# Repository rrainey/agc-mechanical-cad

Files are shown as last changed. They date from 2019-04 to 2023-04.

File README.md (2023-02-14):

# AGC Mechanical CAD Models and Drawings

This repository contains downloadable Autodesk Fusion 360 and STEP CAD models of many Apollo Guidance Computer components.

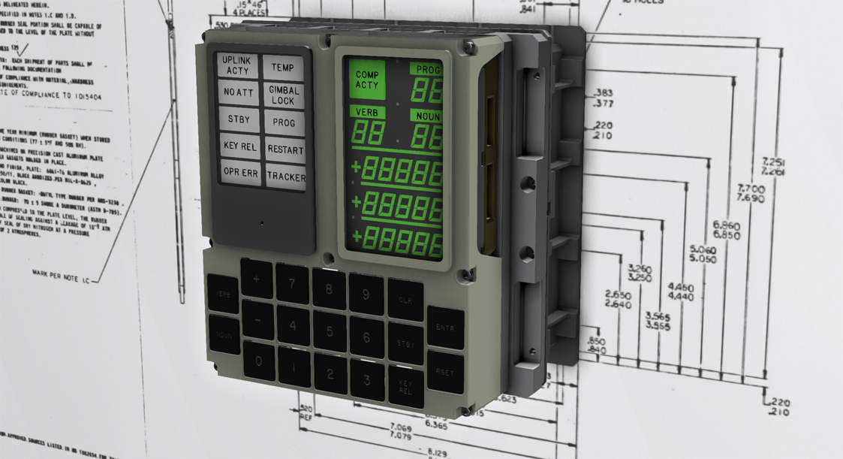
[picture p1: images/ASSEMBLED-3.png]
Assembled Model


## Introduction

The Apollo Guidance Compuer (AGC) is one of the critical inventions that made the U.S. moon landings possible. AGC's were installed in both the Apollo Command Module and Lunar Excursion Module. MIT and NASA archives, as well as important contributions from some
of the original team members have given us a rich set of detail about how this computer was constructed.

The [Virtual AGC Project](https://www.ibiblio.org/apollo/) was originally focused on software simulation 
of the AGC. 

Over time, the Virtual AGC Project branched in many directions. Simulation projects for other space related guidance systems
were researched; hybrid hardware and software models of the AGC have been created. The circuitry of the AGC has been reproduced using modern IC components. 

More recently, Ron Burkey, the Virtual AGC project's leader, scanned, cataloged, and published
the [original MIT electrical and mechanical drawings of the AGC](https://www.ibiblio.org/apollo/ElectroMechanical.html). This detailed catalog has made it possible to construct CAD models of the AGC's mechanical components.

The content in this repository represents my work using Fusion 360 to generate CAD models from those original drawings using modern CAD/CAM tooling.

## How These Models Were Created

[Autodesk's Fusion 360](https://www.autodesk.com/products/fusion-360/students-teachers-educators) was used exclusively to create these models. 
While Fusion 360 is not open source software, Autodesk offers a no-cost
license to students, makers, and startups. You can obtain your own copy of Fusion 360 and begin editing the .f3d files contained in this project. 
STEP-format CAD models for each component have been exported and included in this project as well. 
Those model files are directly usable by many other CAD modeling and 3D-printing systems.

Panel markings use an engraving font face called "Gorton". Eugene Dorr created OTF and TTF versions of these fonts. These files can be downloaded from https://github.com/ehdorrii/dsky-fonts 

### Archived Drawings Collections are Incomplete

It is worth saying that the source archives for this project are incomplete.
The AGC evolved substantially over its lifetime  -- descriptions of many changes
are captured in Engineering Change Proposals (ECPs) which may or may not be completely
reflected in the archived drawings. Also, there are gaps in the drawing collections.  
This requires reconstruction of some parts in order to develop a more complete model.

## Is This a Complete AGC Model of what is Available?

No. I am releasing what I have transcribed so far. That amounts to roughly twenty models. Each is currently 90-100% completely encoded from the original engineering documents.

I'm working to maintain engineering precision wherever I can. Errors undoubtedly exist, and I'm my own Quality
Assurance department currently. In other words, use at your own risk.

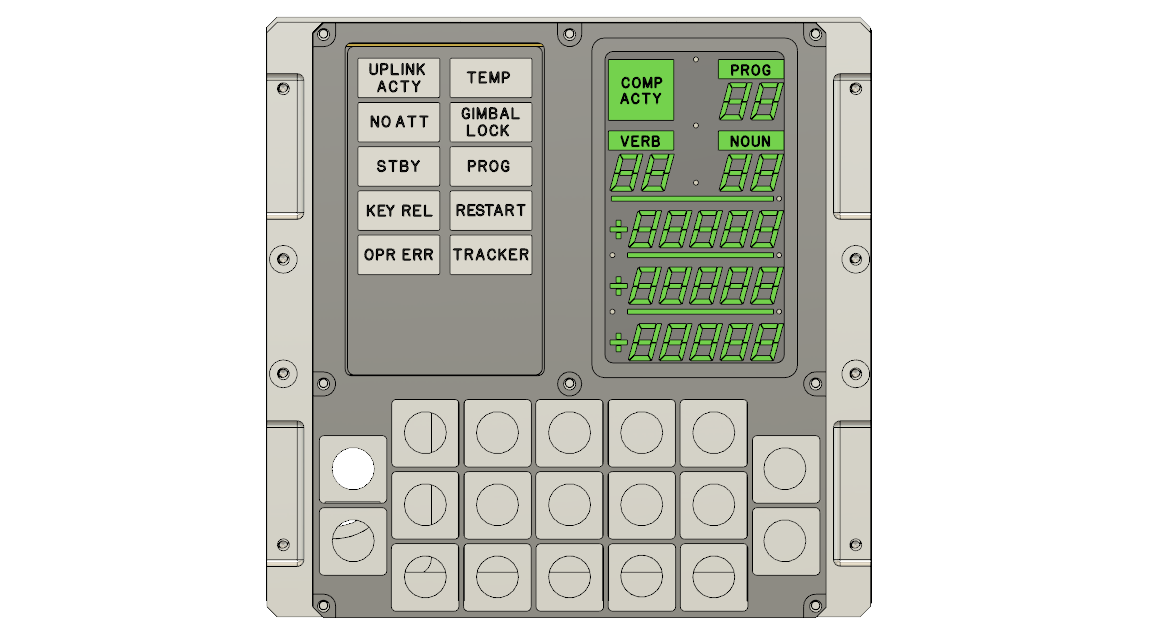
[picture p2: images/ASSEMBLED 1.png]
Assembled Model


## The DSKY: Pushbutton Springs and "Fire Fixes"

An example illustrating the resources and gaps we work from is the DSKY pushbutton
switch. There are three distinct part numbers representing different variants of
the pushbutton switch: 2003875, 2003894, and 2003984.  Of those three only 2003875
has a mostly complete set of drawings.

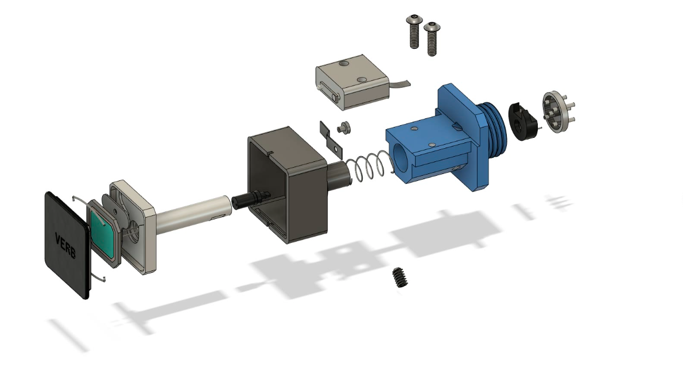
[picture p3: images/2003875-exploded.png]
An AGC Pushbutton - 2003875


The gap starts with the cap housing assembly.  The cap housing sits behind the
actual key cap. It holds the cap in place and serves to guide the depressed key into contact
with the actual switch. The drawing for that cap housing assembly is - so far - missing. Also missing is a
drawing for the leaf spring that's mounted at the back of that assembly.  There's a rivet
attaching the spring to the housing, too.  The exploded drawing you see above represents a best guess of the dimensions of the missing parts.

On my to-do list for this project is to build a 
compendium of what parts we have, where
we had complete drawings to work from, and
where the gaps and guesses are.

[This Raytheon contractor report](https://ntrs.nasa.gov/citations/19700015154) describes important
upgrades to the DSKY that are not completely captured in the archived drawing collections:

>h. DSKY pushbutton switch spring - Due to failures of the DSKY
pushbutton switch spring (shown in Figure 3-6) a failure analysis and
design review of the spring was performed. The failure inalysis and
design review indicated that in normal use the spring could crack at
points of stress concentration. As a result, a new spring was designed.
As shown in the drawing, the new spring replaces the present
spring in form, fit, and function with tighter geometric constraints.

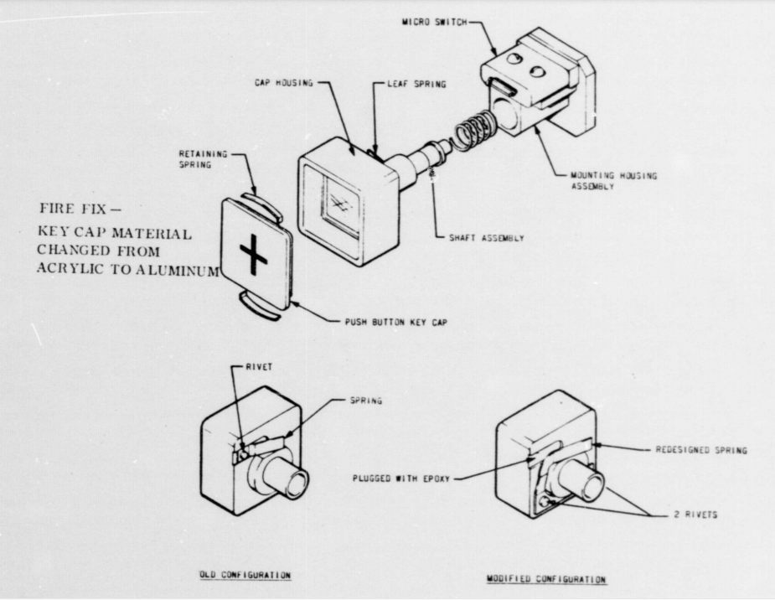
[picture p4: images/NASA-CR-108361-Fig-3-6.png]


>The wraparound design of the new spring lengthens the spring arm
to reduce stress and allows the new spring to be incorporated in the existing
pushbutton switch design. The thickness of the spring has changed from
0.010 to 0.018 inch to retain the same spring rate. The material of the
new spring is the same as that for the present spring but is specially
hardened to a minimum of 270,000 lbf/in^2 U.T.S. to increase the fatigue
strength of the spring.
>
>i. DSKY fire fix - As a result of the
 flammability study performed as authorized by CCA 497-0428, the DSKY alarm indicator(P/N 1006387-003) and DSKY pushbutton caps (P/N 1006353) requiredmaterial changes as follows (see Figure 3-7)
>
>>1. alarm indicator - affix nonflammable nonreflective glass
cover with an aluminum frame as an integral part of the indicator panel
>>2. DSKY pushbutton caps - rep:ace the acrylic cap with one of aluminum having etched and acrylic filled characters.

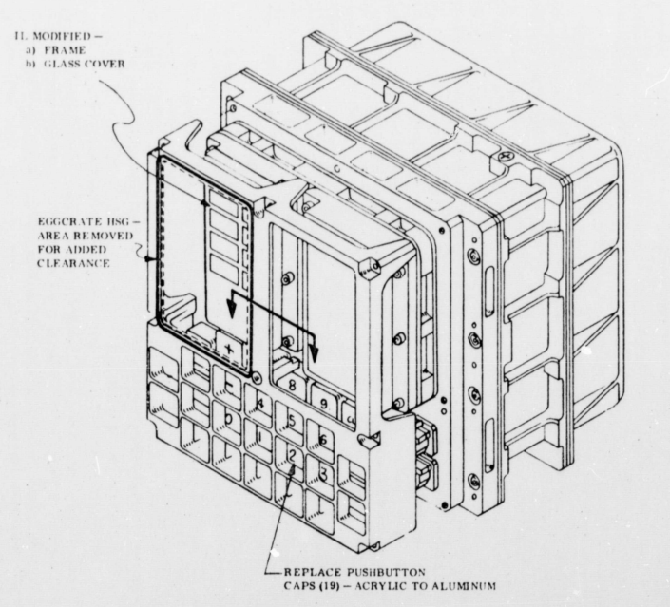
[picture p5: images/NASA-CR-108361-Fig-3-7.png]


>j. Teflon - (not included here, as it dosen't directly apply to the Fusion CAD models, but Teflon coatings were added to reduce the tendency for pushbuttons operate less smoothly due to wear.)

These changes are listed here but not yet integrated into this CAD project.

## My Background

My name is Riley Rainey. I'm a software developer by profession. I spent a number of years building aerospace simulations as my day job.
I'm not a Professional Engineer by any stretch, but my work in simulation put me in close contact with CAD designers and CAD systems. I used AutoCad many years ago, but my exposure to Fusion 360 began with this project.

## Getting Support

There's no official support available, but if you notice a problem or have a request for a specific drawing to be
transcribed, [create an issue](https://github.com/rrainey/agc-mechanical-cad/issues) in this GitHub project.

  
This work is licensed under a [Creative Commons Attribution-ShareAlike 4.0 International License](http://creativecommons.org/licenses/by-sa/4.0/).

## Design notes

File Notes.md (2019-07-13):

Over time the AGC Block II DSKY had multiple versions. There's also different variants installed in the CSM and LEM.

For now, I am focusing on modeling the versions used in the Apollo 17 CSM DSKY (see https://www.ibiblio.org/apollo/2014999-181.html)

I'm collecting notes and questions regarding each drawing set that I used to create this model.

### GENERAL NOTES

Dowel pins are generally not included in these models.

Holes for screw thread inserts are modeled as the actual screw hole.

### 1001489-59 SCREW

Eight of these screws secure the Front Cover on the DSKY ASSEMBLY (in 2003994J).  The latest specification drawing for these screws we currently have is 1001489 "C" - the highest screw suffix on that drawing 
is "-57", not "-59". I did a bit of reverse engineering to reconstruct the "-59" part: #6 threads are used and the length I chose is 1.500 inches.  
At some point I will try to locate a replacement off-the-shelf part from Grainger or Digikey.

### 1006387D - INDICATOR, ALARM

The inner constructon of this assembly is not fully documented in the AGC drawings. I'm generating an "exact" version based on the drawing, and a "reconstructed" version that would be based on building a simulated version from
modern parts.

Portions of the connector at the back of the part remain to be modeled.

On the back, there's a channel marked "0.615 MIN" (B3) - a more "to scale" value of 0.515 MIN has been used in the model.

### 2004699A - COVER

There are apparently two variants of this part, but the drawing does not call these out. The drawing depicts a part with a "short window" -- intended for the Status and Warning light assembly, however a 2004699-001 version is also called out for the E/L & Cover Assembly (2003988B). 
The Status cover assembly(2003897C) calls for either part 2004699-000 or 2004699-001, depending on the variant of the assembly. Based on the two assembly drawing referencing 2004699, I'm inferring that
the -000 variant has the "short window" and -001 is the "tall window". It's not difficult to reconstruct the part geometry for the tall window, but I'm wondering why it is missing in the source part drawing.

### 2004746-001 INDICATOR, DIGITAL (THERMAL-VAC)  (a.k.a. 1006315G)

This is the E/L display indicator for the DSKY. The drawing indicated 2004647 is just a relabeled Block I part, 1006315-001. 1006315G includes dimensions of the E/L display elements and the outline of the assembly, but lacks
details on the internals. The Gorton fonts used in this model originates from Eugene

### 2004923 PLATE, CONNECTOR

[COMPLETE] Screw thread inserts are modeled as a hole for the intended screw. Dowel pins are not modeled. The drawing is slightly out of scale at the middle of the bottom face.

### 2004925 HEADER KEYBOARD MODULE

[COMPLETE] The arrays of holes for the pin insulators aren't explictly marked as laterally centered on the header, but that seems like a reasonable assumption. I have modeled it that way.

### 2004932 JACKING SCREW

[COMPLETE] Both variants are modeled. The modeling of the threading at the tip of the screw isn't quite accurate.

### 2004974D IDM PLATE

[COMPLETE] This is easily the most complex component to model.

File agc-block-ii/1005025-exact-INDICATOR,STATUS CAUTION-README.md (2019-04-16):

thumbnail of model

## thumbnail of model

## 1005025 INDICATOR, STATUS CAUTION - AGC DSKY

This is a model of the Status/Caution Indicator panel of the AGC DSKY.

## Source Drawing(s)

[1005025 sheet 1 of 3](https://archive.org/stream/AgcApertureCardsBatch3Images#mode/1up)

[1005025 sheet 2 of 3](https://archive.org/stream/AgcApertureCardsBatch3Images#page/n1/mode/1up)

[1005025 sheet 3 of 3](https://archive.org/stream/AgcApertureCardsBatch3Images#page/n2/mode/1up)

[2003956](https://archive.org/stream/AgcApertureCardsBatchKeithley#page/n71/mode/1up) AGC DSKY OUTLINE

### Source Drawing Issues

The back view of the assembly on sheet 3 (C2) is out of scale. It is stretched laterally.

### Next Assembly
N/A

## Known Issues
### Model Discrepancies

1. The source drawing does not provide enough detail to accurately reconstruct this assembly.

### To Do List

* This model needs to be decomposed into wells for the lights and a front face.
* The electrical connector remains to be added.

### See Also

N/A

## Credits
This model was created from the original MIT drawings by Riley Rainey (<riley@websimulations.com>)

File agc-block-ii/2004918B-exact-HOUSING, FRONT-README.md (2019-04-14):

thumbnail of model

## 20004918 rev. B - HOUSING, FRONT - AGC DSKY

general notes; if this model is application specific variant of an exact model (e.g., optimized for 3D printing), document the intended use and changes that were applied

## Source Drawing(s)

links to source drawings at the ibilio site

### Source Drawing Issues

None.

### Next Assembly
2003903

## Known Issues
### Model Discrepancies

1. In several places, the source drawing calls for holes to be drilled for threaded inserts rather that the actual threading.  In such places, the required final threading had been modeled instead.
2. The two Pin Dowels are not modeled, nor their insert holes

### To Do List

* Many holes still remain to be modeled

### See Also

MS21209 -- Mil Standard Threaded Inserts

## Credits
This model was created from the original MIT drawings by Riley Rainey (<riley@websimulations.com>)

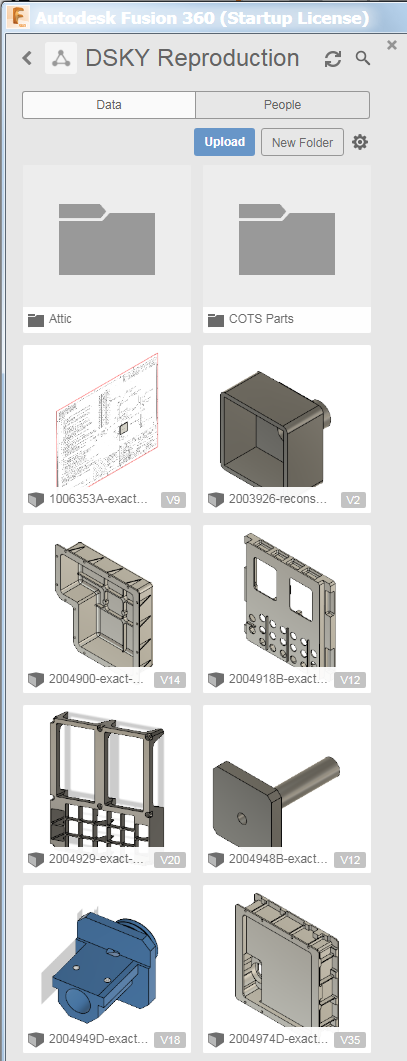
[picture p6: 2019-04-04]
images/f360-shot-01.PNG

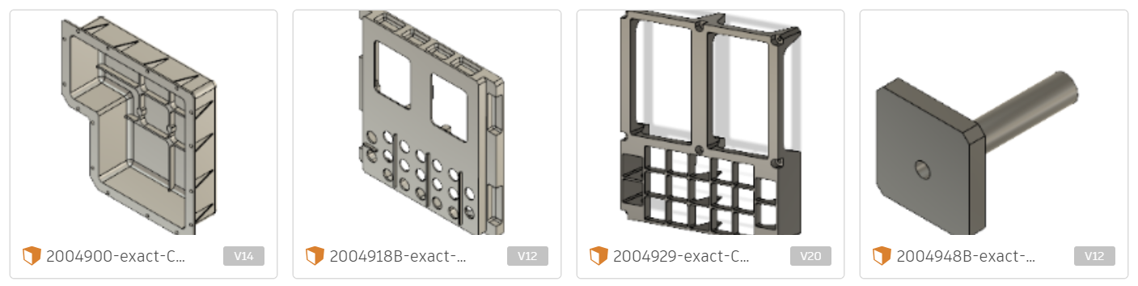
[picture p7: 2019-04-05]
images/f360-shot-02.png

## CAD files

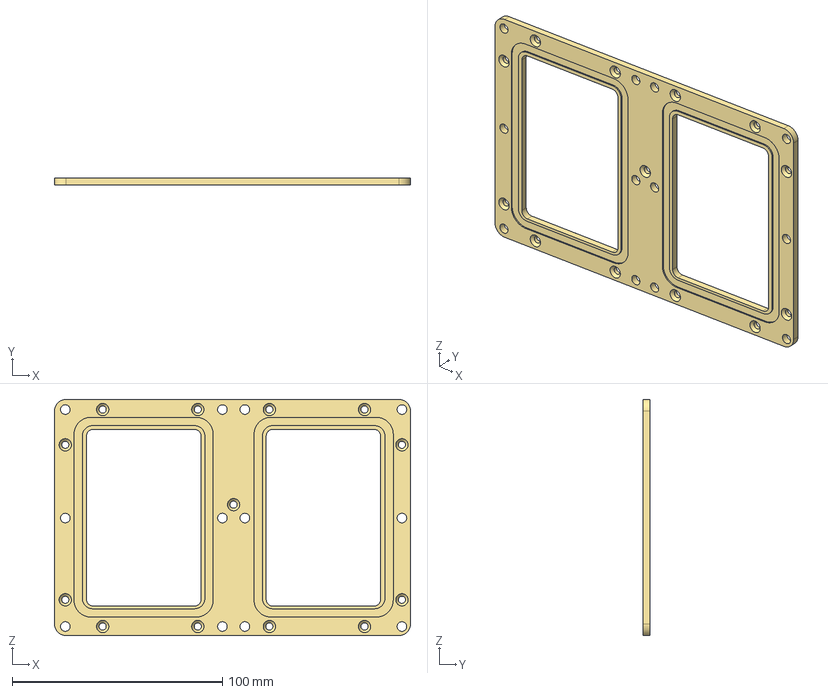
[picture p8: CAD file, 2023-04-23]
agc-block-ii/1006351A-exact-GASKET.step
169.2 x 3.20 x 112.3 mm

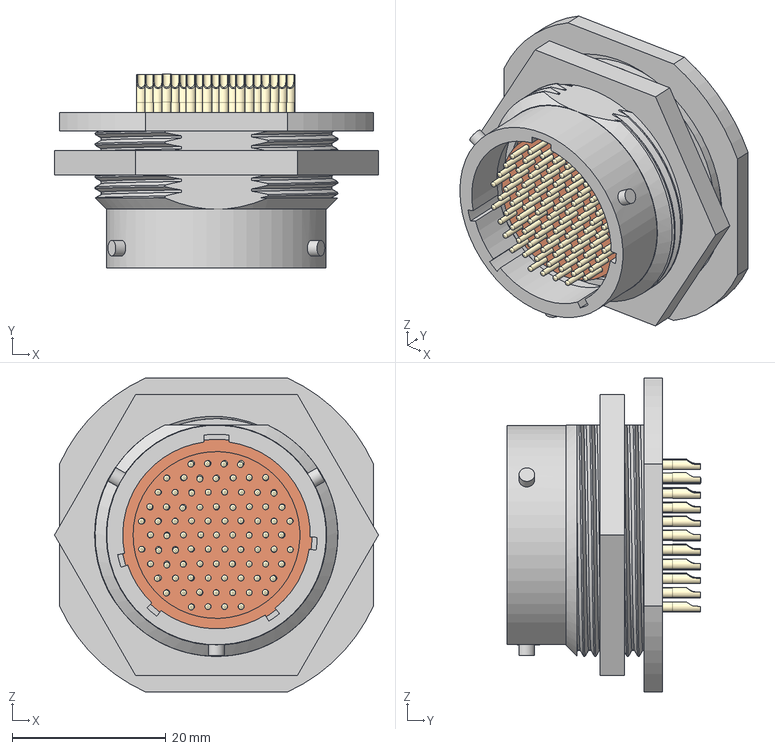
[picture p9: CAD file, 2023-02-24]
agc-block-ii/1006361.step
42.2 x 25.2 x 40.9 mm
Pin x 85

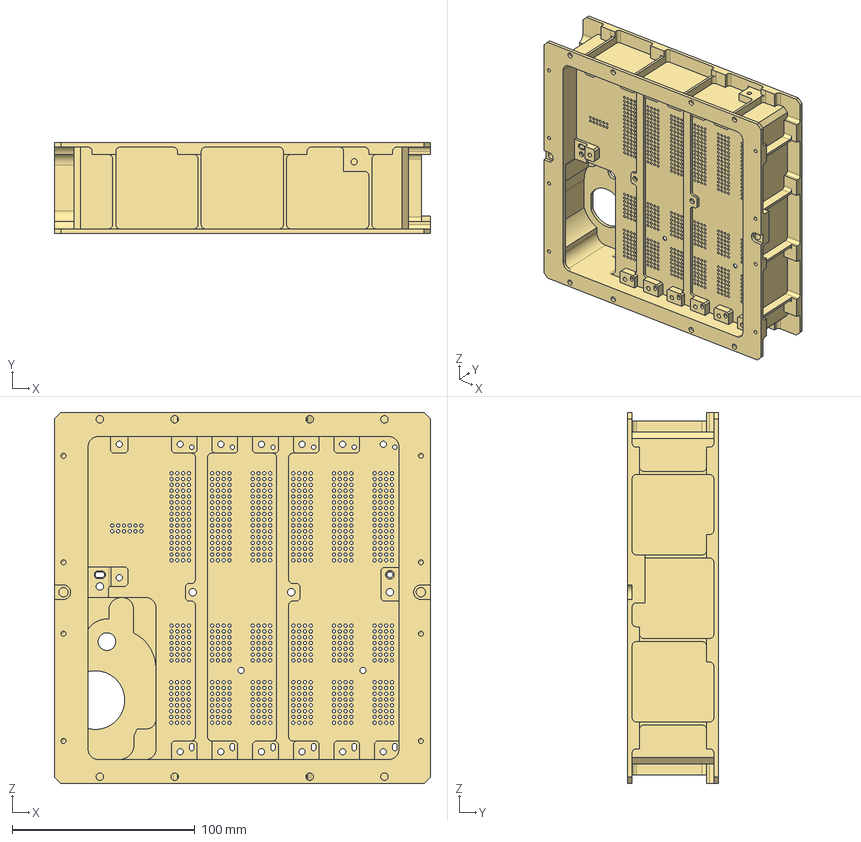
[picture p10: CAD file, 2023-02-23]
agc-block-ii/2004974D-exact-PLATE,IDM.step
205.8 x 49.8 x 203.2 mm

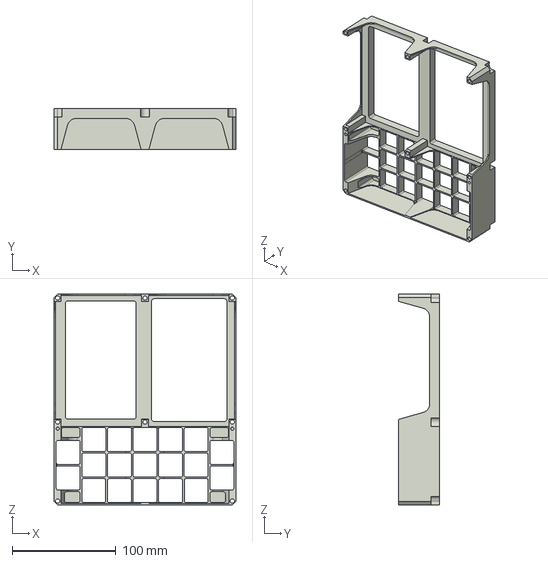
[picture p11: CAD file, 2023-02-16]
agc-block-ii/2004739C-exact-COVER, FRONT.step
175.3 x 39.9 x 203.2 mm

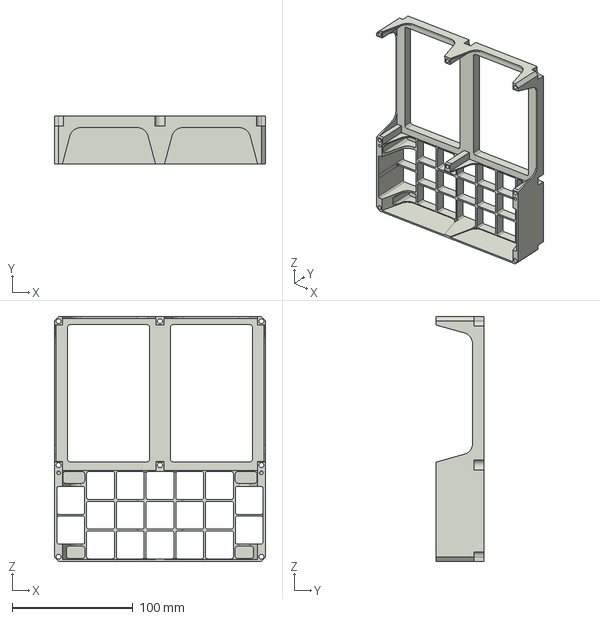
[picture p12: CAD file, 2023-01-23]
agc-block-ii/2004929-exact-COVER, FRONT.step
175.3 x 39.9 x 203.2 mm

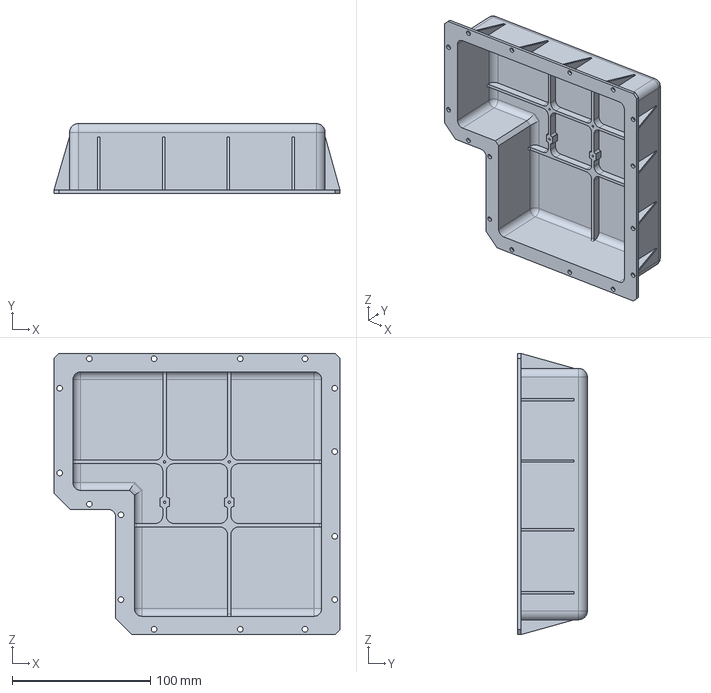
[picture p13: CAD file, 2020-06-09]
agc-block-ii/2004900-exact-COVER,REAR.step
206.6 x 50.4 x 203.1 mm

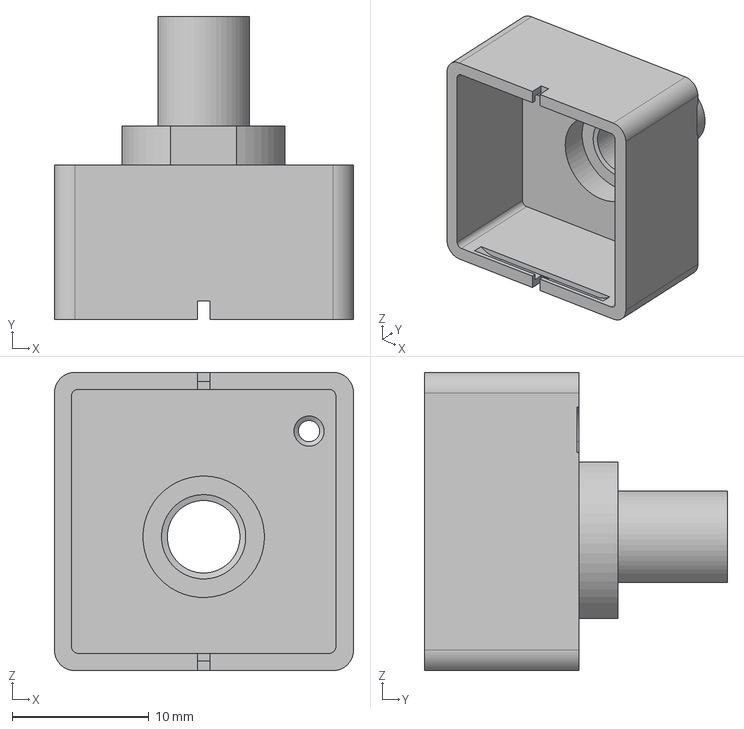
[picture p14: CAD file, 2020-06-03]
agc-block-ii/2004947D-exact-HOUSING, CAP.step
21.9 x 22.2 x 21.8 mm

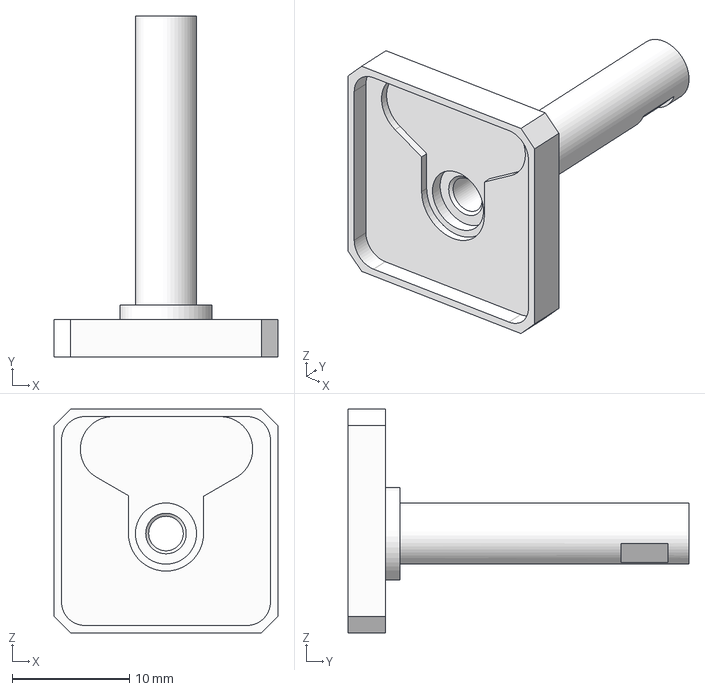
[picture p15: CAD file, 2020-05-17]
agc-block-ii/2004948B-exact-SHAFT.step
19.0 x 29.0 x 19.0 mm

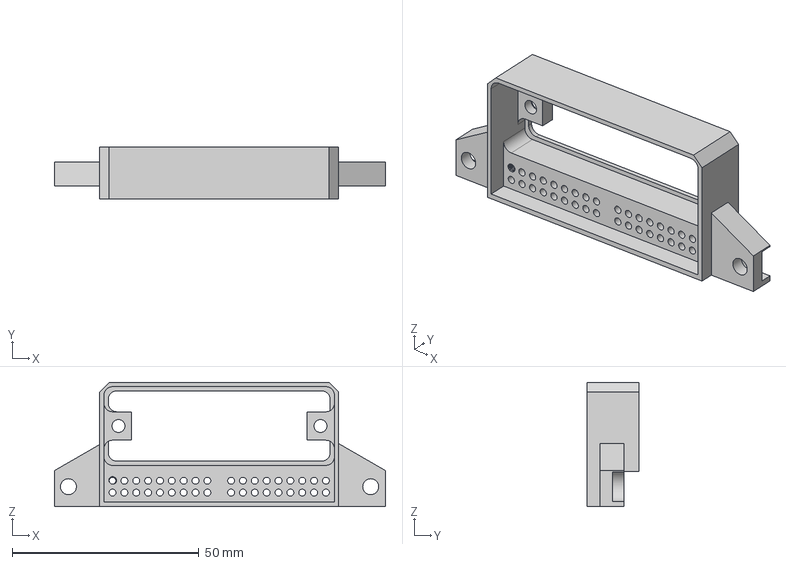
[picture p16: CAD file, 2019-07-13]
agc-block-ii/2004925-HEADER KEYBOARD MODULE.step
88.6 x 14.0 x 33.3 mm

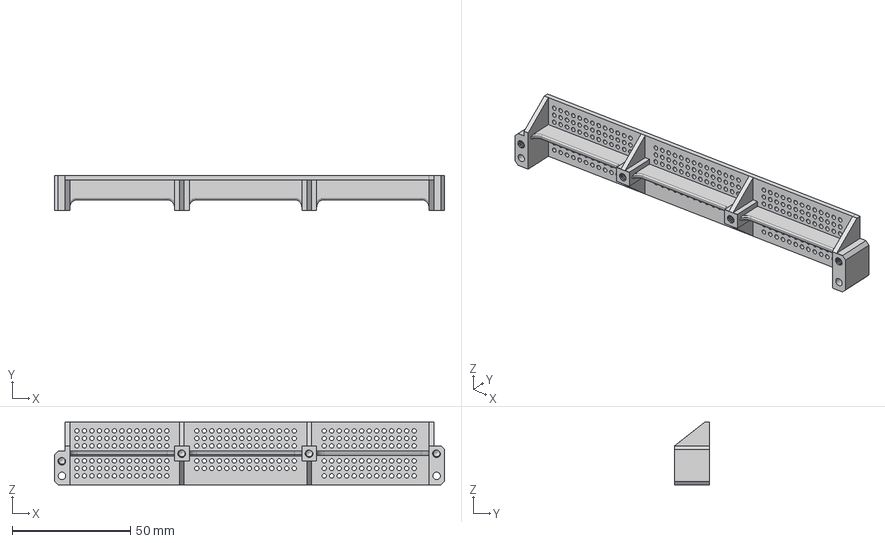
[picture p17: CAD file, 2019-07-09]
agc-block-ii/2004923A-PLATE, CONNECTOR v4.step
165.2 x 15.0 x 26.7 mm

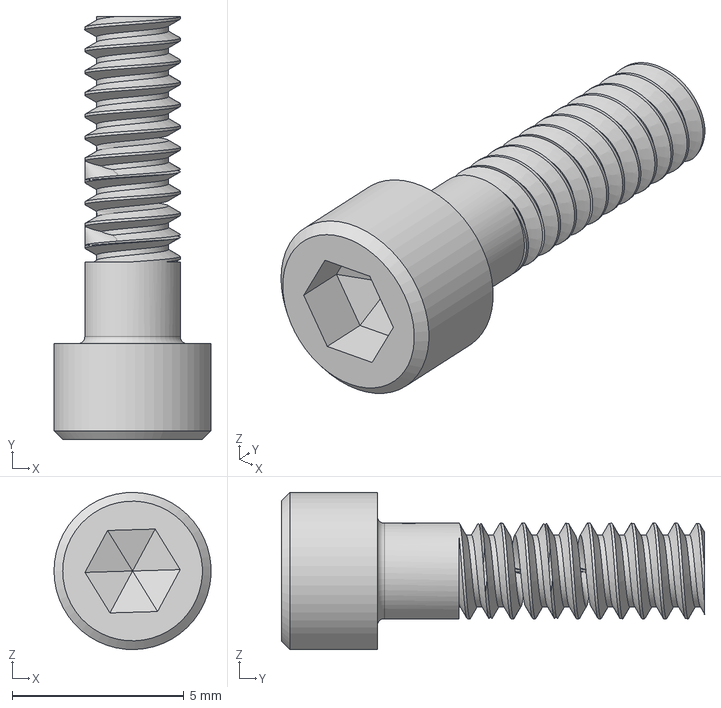
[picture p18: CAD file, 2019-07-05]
agc-block-ii/MS16995H-10-exact.step
4.57 x 12.3 x 4.57 mm

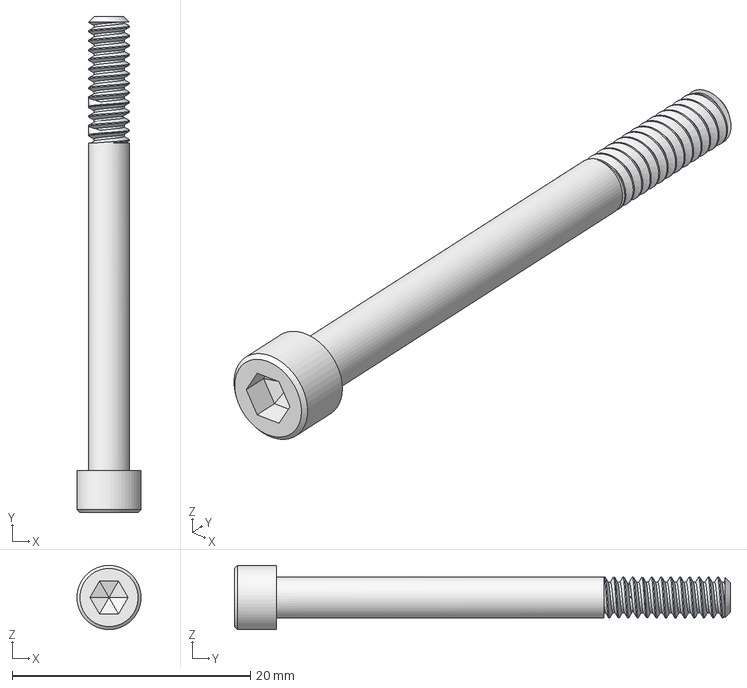
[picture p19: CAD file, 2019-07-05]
agc-block-ii/1001489C-59-reconstructed.step
5.38 x 41.6 x 5.38 mm

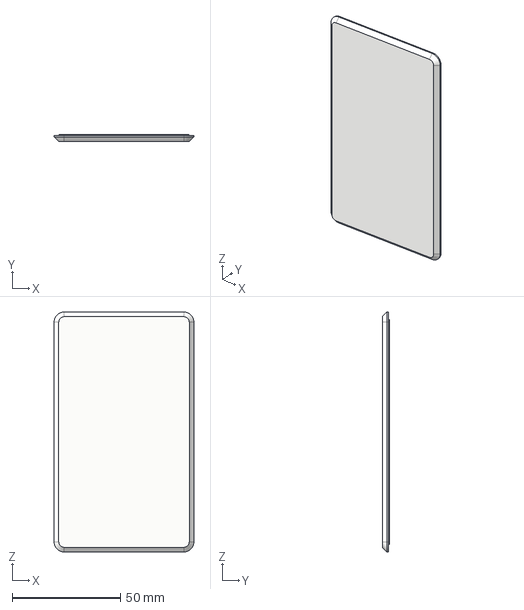
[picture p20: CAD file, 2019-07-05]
agc-block-ii/2004745-exact-PANEL, INDICATOR EL.step
64.5 x 3.40 x 110.7 mm

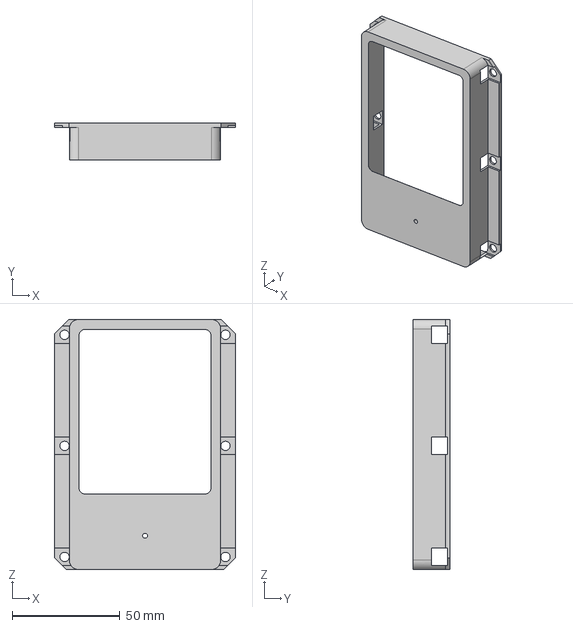
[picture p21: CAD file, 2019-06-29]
agc-block-ii/2004699A-000-exact.step
84.2 x 17.0 x 116.1 mm

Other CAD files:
agc-block-ii/2004947D-HOUSING, CAP-exact.step
agc-block-ii/2004699A-001-exact.step
agc-block-ii/1006315G-exact.step
agc-block-ii/1006349-exact-GASKET, RETAINED.step
agc-block-ii/1001489C-59-reconstructed.f3d
agc-block-ii/1005025-exact-INDICATOR,STATUS CAUTION.step
agc-block-ii/1006349-exact-GASKET, RETAINED.f3d
agc-block-ii/1006350A-exact-GASKET, RETAINED.f3d
agc-block-ii/1006350A-exact-GASKET, RETAINED.step
agc-block-ii/1006351A-exact-GASKET.f3d
agc-block-ii/1006353A-exact-CAP.f3d
agc-block-ii/1006353A-exact-CAP.step
agc-block-ii/2003926-reconstructed-HOUSING.step
agc-block-ii/2004699A-000-exact.f3d
agc-block-ii/2004699A-001-exact.f3d
agc-block-ii/2004699A-exact.f3d
agc-block-ii/2004699A-exact.step
agc-block-ii/2004699B-exact.f3d
agc-block-ii/2004699B-exact.step
agc-block-ii/2004745-exact-PANEL, INDICATOR (EL).f3d
agc-block-ii/2004745-exact-PANEL, INDICATOR EL.f3d
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

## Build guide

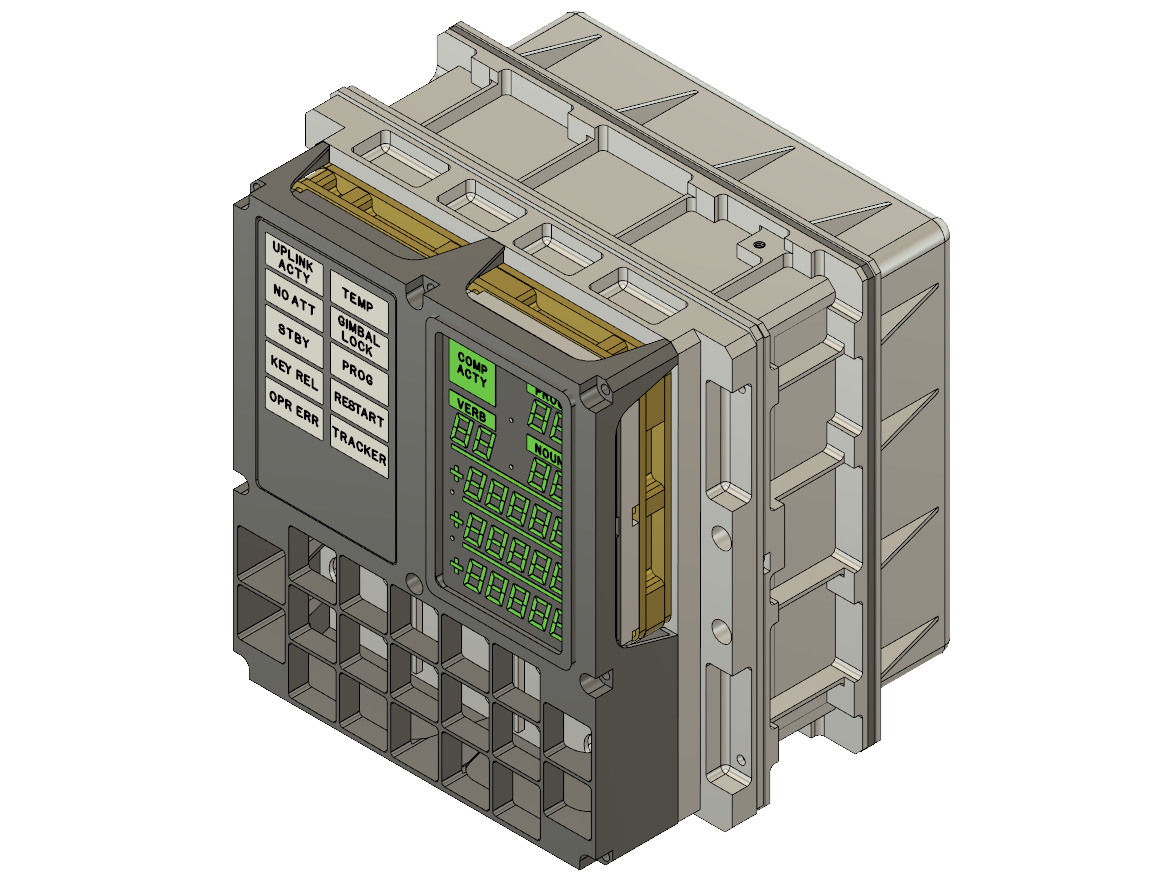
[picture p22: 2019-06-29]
images/ASSEMBLED 2.png

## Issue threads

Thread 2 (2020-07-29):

No Issue

bschymanski, 2020-07-29:
Hi,

i have no issue at all and want to thank you for making these files available!

Fantastic work. I enjoy working with them in Fusion360 to prepare them for 3d printing and adjusting little things so i can assemble them with M3 Screws for example.

All the best

Bernd

rrainey, 2020-07-29:
I'm glad to read you are enjoying this work.  I am creating a project derived from this repo specifically for 3D printing.  It would include versions of these models with appropriate insert holes and other Additive Manufacturing optimizations like I think you are describing.  It would allow for using Ben Krasnow's EL display along with my Alarm Panel and modular keyboard replica projects.

If you are interested in collaborating, let me know.

bschymanski, 2020-07-29:
I printed the parts for one of the buttons and they work great mechanically! But i have to design a screw (?)  to fix it to the Housing.

Also printed the "2004918B-exact-HOUSING, FRONT" in one piece. It worked, but i didn't like the fact that i had to use supports.
I split the model in half and right now i am printing the second half to see if they fit together afterwards.
On the left side is not enough "flesh" for 3D printig and there are two gaps (i attached you a photo to make clear what i mean)
I tried to fix it, but there are dependencys that i have to understand better.

But i am by no means a gifted Fusion360 user nor a programmer of any sorts, but i own one of the OpenDSKY Kits. It works and is close to the original, but not exactly.
Don't like the buttons of the though.

But the people in the OpenDSKY Google Group are nice and they started to build a more realistic model. And they are in the process of creating an alternativ EL Display, but haven't released the PCB files yet.

The EL-Display is the biggest problem i guess. Ben Krasnow's EL display would be great to have, but i would not know how to build it on my own. The process is quite demanding.

Might i mention your work in the OpenDSKY Group? (https://groups.google.com/forum/#!forum/opendsky)

Bernd

(Sorry for my english, i am not a native speaker)

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

bschymanski, 2020-07-29:
Hi again,
i figured it out with the side, had to use the extrude function instead of the press-pull function.
Now it slices well for both sides. I should have checked the sliced model before printing....

rrainey, 2020-07-29:
Yes. I have seen that issue, although it "prints" without a physical gap on the SLS print process that I use.

It's on my list to examine and repair -- For what it is worth, I have been trying to maintain fidelity with the original drawings in all cad models.  There is probably some measurement in that overall model that's simply not to spec with the original drawing.  If it's OK with you, I will create a separate issue to track resolution of this problem.

There is also a more minor issue with the Front Cover part that I need to address. It is easy to fix after printing, so it is maybe less urgent.  I'll open an issue on that tonight as well.

Feel free to share your experiences here with other project teams. I'm happy to collaborate where I have time. On the EL Display side, I have been building several copies of Ben Krasnow's display. I'm planning to complete the final stack-up this week. Maybe I can post some videos if it works for me as well as it did for him.

rrainey, 2020-07-30:
I committed what I hope is a fix. Have a look.

Closed 2023-03-28.

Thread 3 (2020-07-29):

2004929 Front Cover - extra ribs must be removed

rrainey, 2020-07-29:
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

The circled areas almost certainly don't exist in the actual part. On one side, the presence of these ribs impinges on one of the  Push Button installation ribs on the Front Housing (2004918B)

rrainey, 2020-07-30:
Fix committed.

Closed 2020-07-30.

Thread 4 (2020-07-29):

2004918B Front Housing - right side wells too close to edge

rrainey, 2020-07-29:
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
The two wells (circled) are place too close to the right edge of the piece. This leave the rightmost wall too thin for most 3D printing processes.

rrainey, 2020-07-30:
I have committed a candidate fix.

bschymanski, 2020-07-30:
That looks much better, i am pretty shure it will print OK

Closed 2020-07-30.

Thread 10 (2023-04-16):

Gasket 1006351A, spaces for indicators not centered

lathoub, 2023-04-16:
Hi,
I believe that the holes in [Gasket 1006351A](https://github.com/rrainey/agc-mechanical-cad/blob/master/agc-block-ii/1006350A-exact-GASKET%2C%20RETAINED.f3d) for the indicators are not centered. Unfortunately, I'm bad at editing in Fusion 360, as I would have centered it myself.

Am I seeing it right?
Thanks!

The reference drawing indicates a distance of 0.080 inch, but in the drawing the distance vary from 0.082 to 0.02 inch.

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

(When I overlay the printed 1006351A over [2004968E](https://github.com/rrainey/agc-mechanical-cad/blob/master/agc-block-ii/2004968E-exact-HOUSING%2C%20FRONT.f3d), the holes for the indicators are also not centered).

rrainey, 2023-04-18:
I'll have a look at it this week.

rrainey, 2023-04-23:
I pushed a fix for the issue on the left side cutout.  Have a look.

lathoub, 2023-04-23:
Perfect - thanks @rrainey

Closed 2023-04-23.

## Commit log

2019-04-04 Initial Import
    [1006353A-exact-CAP.f3d, 1006353A-exact-CAP.step, 2003926-reconstructed-HOUSING.step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]
2019-04-06 Added critical threaded and other holes.
    Threaded inserts are not yet modeled.
2019-04-14 Added some screw holes to 4974; add readme for 4918
    [2004974D-exact-PLATE,IDM.step]
2019-04-14 Update 2004918B-exact-HOUSING, FRONT-README.md
2019-04-15 First cut of DSKY Status/Cation indicator
    [1005025-exact-INDICATOR,STATUS CAUTION.step]
2019-04-28 Several minor additions to key shaft, key housing, and front cover
    [2003926-reconstructed-HOUSING.step, 2004929-exact-COVER, FRONT.step, 2004948B-exact-SHAFT.step]
2019-04-29 Add notches on shaft
    [2004948B-exact-SHAFT.step]
2019-04-29 Add pressure relief screw hole
    [2004974D-exact-PLATE,IDM.step]
2019-04-29 Fix screw hole for front cover's lower left attach point
2019-04-30 Added two missing screw holes attaching front cover
    [2004974D-exact-PLATE,IDM.step]
2019-05-02 Added and adjusted screw holes. Tweaked top struts on Front Cover for clearance.
    [2004929-exact-COVER, FRONT v3.step]
2019-05-02 Fixed a couple of file naming issues
    [2004929-exact-COVER, FRONT v3.step, 2004929-exact-COVER, FRONT.step]
2019-05-15 Added Gasket plate.
    [1006351A-exact-GASKET.f3d, 1006351A-exact-GASKET.step]
2019-06-16 Added rough versions of gaskets, EL indicator, alignment fixes
    [1006315G-exact.step, 1006349-exact-GASKET, RETAINED.f3d, 1006349-exact-GASKET, RETAINED.step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]
2019-06-26 Added labels to the E/L display
    [1006315G-exact.step]
2019-07-05 Add a few hex screws. E/L INDICATOR updates
    [1001489C-59-reconstructed.f3d, 1001489C-59-reconstructed.step, 2004745-exact-PANEL, INDICATOR EL.f3d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]
2019-07-06 Refinements to the interior of the IDM PLATE 2004947
    [2004974D-exact-PLATE,IDM.step]
2019-07-06 Update notes on IDM PLATE
2019-07-06 Raise mounting position near section F-F
    [2004974D-exact-PLATE,IDM.step]
2019-07-07 Added wire wrap holes to IDM PLATE
    [2004974D-exact-PLATE,IDM.step]
2019-07-09 Finish IDM Plate
2019-07-09 Add 2004923 - CONNECTOR PLATE
    [2004923A-PLATE, CONNECTOR v4.step, 2004923A-PLATE, CONNECTOR.f3d]
2019-07-13 Add HEADER for KEYBOARD MODULE
    [2004925-HEADER KEYBOARD MODULE.f3d, 2004925-HEADER KEYBOARD MODULE.step]
2019-07-13 Add missing holes
2020-05-17 Add 2004947D CAP HOUSING
    [2004947D-exact-HOUSING, CAP.step]
2020-05-17 Added countersink in 2004948 shaft; part of the PUSHBUTTON
    [2004948B-exact-SHAFT.step]
2020-05-18 Add countersink in 2004947
    [2004947D-HOUSING, CAP-exact.step]
2020-06-03 Added 2004947D-exact-HOUSING, CAP; fixed right wall thickness in 2004974D-exact-PLATE,IDM
    [2004947D-exact-HOUSING, CAP.step]
2020-06-09 Removed the thread modeling of all threaded holes
    [2004900-exact-COVER,REAR.step]
2020-07-30 Issue #3 2004929 Front Cover - extra ribs must be removed
    [2004929-exact-COVER, FRONT.step]
2023-01-22 Add 2004968 - front housing
2023-01-23 add revised front cover - with dowel pin holes
    [2004929-exact-COVER, FRONT.step]
2023-01-29 Add assembly model of DSKY pushbutton
2023-02-02 Update 2003875 SWITCH ASSY; adjust hierarchy and add a couple of components
2023-02-12 refine leaf spring in 2003875
2023-02-16 fix problem at back of front housing and add post-fire front cover
    [2004739C-exact-COVER, FRONT.step]
2023-02-23 fix an issue near the cutout for the electrical connector
    This is not 100% fixed yet.
    [2004974D-exact-PLATE,IDM.step]
2023-02-23 further improvements to space for connector on IDM PLATE 2004974
    [2004974D-exact-PLATE,IDM.step]
2023-02-24 add 1006361 CONNECTOR
    [1006361.step]
2023-04-23 Fix for issue #10
    [1006351A-exact-GASKET.f3d, 1006351A-exact-GASKET.step]

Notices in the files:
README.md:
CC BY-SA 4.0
